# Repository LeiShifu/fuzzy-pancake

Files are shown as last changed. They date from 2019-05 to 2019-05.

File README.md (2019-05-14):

# fuzzy-pancake
A micro bi-axial tensile testing machine designed for biological materials。

load speed：0.0001-0.5mm/s 
data range：0.1-1000gf
accuracy：±0.2% of load range

最近比较忙，先传一部分资料，BOM表过一段时间上传，如果真的有想做的请先联系我，有一些问题还是发语音更能说清楚。

其实双轴拉伸机原理很简单，两边夹具恒速度往外拉伸，再加个力传感器测拉力就好。
至于为什么用arduino，因为确实省事。。。

设计思路：机械部分+控制部分

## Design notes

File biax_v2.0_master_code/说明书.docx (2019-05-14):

0-8这几个数字的功能和以前的sv，sr，n，p，l一样。。。

a-w用来设置速度

默认的速度为0，默认的预加载拉力为10g

例如：设置y轴速度为0.1mm/s就在串口输入AE （A:设置y轴速度为0，E：y轴速度+0.1mm/s）

默认x和y轴都会动，恒速度加载再输入1就行

如果在加载中途y轴要改成0.01mm/s的话输入AH1(A:设置y轴速度为0，H：y轴速度+0.01mm/s，1：在这里的作用是更新速度，如果没输入1的话拉伸机夹具的速度还是0.1mm/s)

case 0:motor_stop();motor_start_flag=0;break;//模式0,电机停止(停止加载)

case 1:motor_start_flag=motor_start(SetSpeed);break;//模式1，恒速度加载

case 2:start_run_force_flag=1;break; //模式2，恒力加载

case 3:start_run_repetition_flag=1;break;//模式3，预加载

case 4:motor_start_flag=1;break; //模式4，输出数据

case 5:motor_start_flag=0;break; //模式5，停止输出数据

case 6:reset_zero_flag=1;break; //模式6，位置归零

case 7:calibrate_flag=1;break; //模式7，传感器归零

case 8:reverse_dir_flag=1;break; //模式8，反向

小写字母(a-w)设置x轴的值，大写字母(A-W)设置y轴的值。

case 'a':x_start(20);break; //设置x轴速度为0

case 'b':x_start(21);break; //设置x轴速度加1mm/s

case 'c':x_start(22);break; //设置x轴速度加0.5mm/s

case 'd':x_start(23);break; //设置x轴速度加0.2mm/s

case 'e':x_start(24);break; //设置x轴速度加0.1mm/s

case 'f':x_start(25);break; //设置x轴速度加0.05mm/s

case 'g':x_start(26);break; //设置x轴速度加0.02mm/s

case 'h':x_start(27);break; //设置x轴速度加0.01mm/s

case 'i':x_start(28);break; //设置x轴速度加0.005mm/s

case 'j':x_start(29);break; //设置x轴速度加0.002mm/s

case 'k':x_start(30);break; //设置x轴速度加0.001mm/s

case 'l':x_start(31);break; //设置x轴速度加0.0005mm/s

case 'm':x_start(32);break; //设置x轴速度加0.0002mm/s

case 'n':x_start(33);break; //设置x轴速度加0.0001mm/s

case 'o':x_start(40);break;//设置x轴最大拉力为0(应力松弛实验才会用到）

case 'p':x_start(41);break; //设置x轴最大拉力加50g

case 'q':x_start(42);break; //设置x轴最大拉力加20g

case 'r':x_start(43);break; //设置x轴最大拉力加10g

case 's':x_start(44);break; //设置x轴最大拉力加5g

case 't':x_start(45);break; //设置x轴最大拉力加2g

case 'u':x_start(46);break; //设置x轴最大拉力加1g

case 'v':x_start(47);break; //设置预拉伸拉力为0

case 'w':x_start(48);break; //设置预拉伸拉力加1g

拉伸机上有夹具的轴是y轴，所以这两行命令应该不用管。。。

case 'X':y_enable=0;break; //停用y轴（单轴拉伸）

case 'Y':y_enable=1;break; //启用y轴（双轴拉伸）

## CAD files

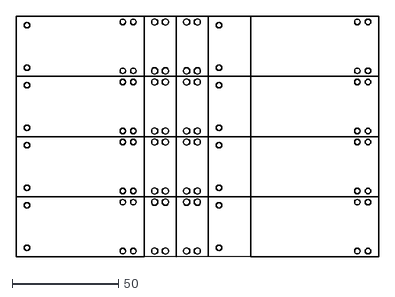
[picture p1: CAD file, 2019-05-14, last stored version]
Drawing2.dxf
170.4 x 112.8

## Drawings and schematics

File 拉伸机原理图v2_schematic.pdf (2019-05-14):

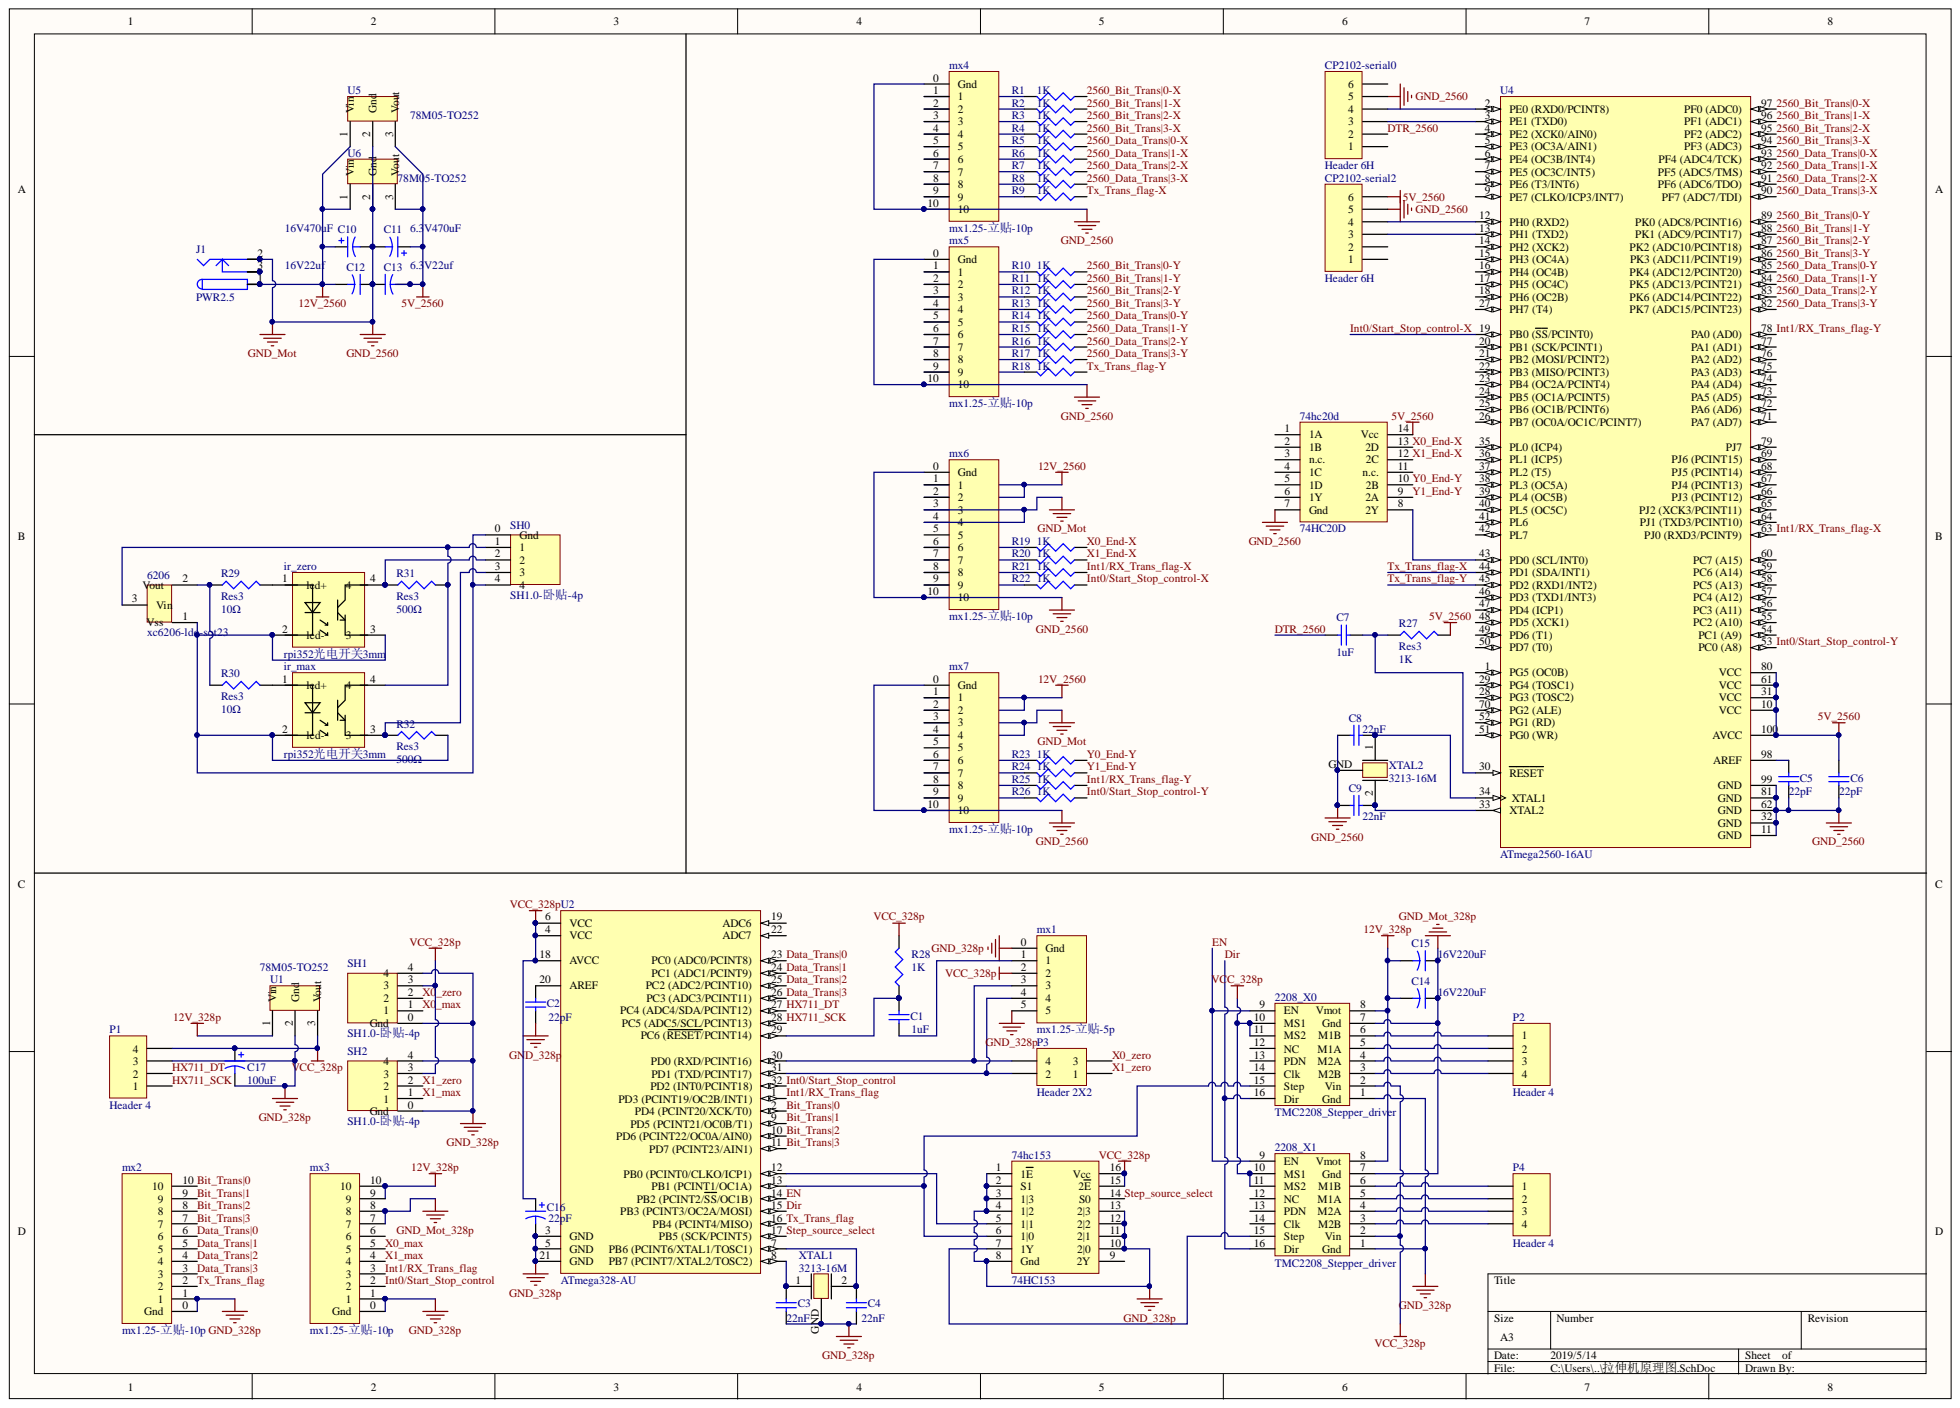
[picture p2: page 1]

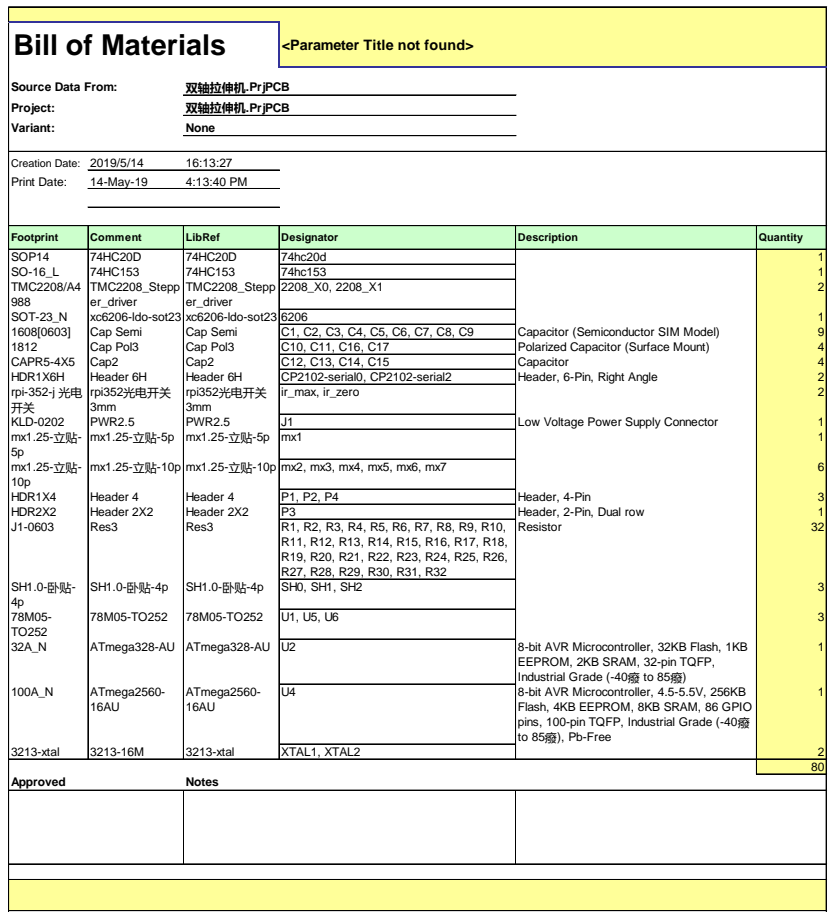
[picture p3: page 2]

EEPROM, 2KB SRAM, 32-pin TQFP,
Industrial Grade (-40癈 to 85癈)

Flash, 4KB EEPROM, 8KB SRAM, 86 GPIO
pins, 100-pin TQFP, Industrial Grade (-40癈
to 85癈), Pb-Free

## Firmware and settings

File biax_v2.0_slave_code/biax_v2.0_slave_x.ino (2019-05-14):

#include "HX711.h"
#include "STEP.h"

void runcountrol();
void SendForce();
void init_conmunication_io();
void start_run_repetition();
void start_run_force(double force_speed);
long get_data();

uint8_t recieved_data[8];
uint8_t force_data[4];
uint8_t Bit;
double SetSpeed=0,SetForce=0,SetPreForce=100;

bool motor_start_flag=0;
bool start_run_flag=0;
bool start_run_repetition_flag=0;//预加载
bool start_run_force_flag=0;     //恒力加载
bool reset_zero_flag=0;          //位置归零
bool calibrate_flag=0;           //校准
bool reverse_dir_flag=0;         //反向

void setup(){
  init_motor_io();
  Init_Hx711();
  init_conmunication_io();
  attachInterrupt(0, runcountrol,RISING);
  calibrate();
  reset_zero();
}

void loop(){
  if(motor_start_flag){
    long Force=Get_Force();
    if(Force>0){
      force_data[0]=Force%10;
      Force/=10;
      force_data[1]=Force%10;
      Force/=10;
      force_data[2]=Force%10;
      Force/=10;
      force_data[3]=Force%10;
    }
    else
      force_data[0]=force_data[1]=force_data[2]=force_data[3]=0; 
    SendForce();
    delay(110);
  }
  if(start_run_repetition_flag){  //预加载
    start_run_repetition_flag=0;
    start_run_repetition();
  }
  if(start_run_force_flag){
    start_run_force_flag=0;     //恒力加载
    start_run_force(SetSpeed);
  }
  if(reset_zero_flag){
   reset_zero_flag=0;          //位置归零
   reset_zero();
  }
  if(calibrate_flag){
    calibrate_flag=0;           //校准
    calibrate();
  }
  if(reverse_dir_flag){
    reverse_dir_flag=0;         //反向
    reverse_dir();
  }
}
void runcountrol(){
  DDRD=0x00;
  DDRC=0xf0&DDRC;
  delayMicroseconds(1);
  DDRD=0x00;
  DDRC=0xf0&DDRC;
  delayMicroseconds(1);
  switch((PIND>>4&0x0f)|(PINC<<4&0xf0)){
    case 0:motor_stop();motor_start_flag=0;break;          //模式0，电机停止
    case 1:motor_start_flag=motor_start(SetSpeed);break;    //模式1，恒速度加载
    case 2:start_run_force_flag=1;break;     //模式2，恒力加载
    case 3:start_run_repetition_flag=1;break;//模式3，预加载
    case 4:motor_start_flag=1;break;        //模式4，输出数据
    case 5:motor_start_flag=0;break;        //模式5，停止输出数据
    case 6:reset_zero_flag=1;break;          //模式6，位置归零
    case 7:calibrate_flag=1;break;           //模式7，校准
    case 8:reverse_dir_flag=1;break;         //模式8，反向
    case 20:SetSpeed=0;break;         //设置速度为0
    case 21:SetSpeed+=1;break;        //速度加1mm/s
    case 22:SetSpeed+=0.5;break;      //速度加0.5mm/s
    case 23:SetSpeed+=0.2;break;      //速度加0.2mm/s
    case 24:SetSpeed+=0.1;break;      //速度加0.1mm/s
    case 25:SetSpeed+=0.05;break;
    case 26:SetSpeed+=0.02;break;
    case 27:SetSpeed+=0.01;break; 
    case 28:SetSpeed+=0.005;break;
    case 29:SetSpeed+=0.002;break;
    case 30:SetSpeed+=0.001;break;
    case 31:SetSpeed+=0.0005;break;
    case 32:SetSpeed+=0.0002;break;
    case 33:SetSpeed+=0.0001;break; 
    case 40:SetForce=0;break;          //设置应力松弛时最大拉力为0
    case 41:SetForce+=500;break;       //最大拉力加50g
    case 42:SetForce+=200;break;       //模式1，恒速度加载
    case 43:SetForce+=100;break;       //模式1，恒速度加载
    case 44:SetForce+=50;break;
    case 45:SetForce+=20;break; 
    case 46:SetForce+=10;break;
    case 47:SetPreForce=0;break;       //设置预拉伸拉力为0
    case 48:SetPreForce+=10;break;     //预拉伸拉力加1g
  }
 DDRD=0b11110000|DDRD;
 DDRC=0b00001111|DDRC;
}

void start_run_force(double force_speed){
  int i=12000;
  long ooo=0;
  motor_start(force_speed);
  while(get_data()<SetForce){
    SendForce();
    delay(100);
  }
  force_speed=force_speed/2;
  while(i>0){
    ooo=get_data();
    if(ooo>SetForce*1.01){
      force_speed=force_speed/2;
      motor_start(force_speed);
    }
    else if(ooo<SetForce*0.99){
      force_speed=force_speed*1.5;
      motor_start(force_speed);
    }
    SendForce();
    delay(100);
    i--;
  }
  motor_stop();
}

long get_data(){
    long nega=Get_Force();
    if(nega>0){
      force_data[0]=nega%10;
      nega/=10;
      force_data[1]=nega%10;
      nega/=10;
      force_data[2]=nega%10;
      nega/=10;
      force_data[3]=nega%10;
    }
    else
      force_data[0]=force_data[1]=force_data[2]=force_data[3]=0; 
    return nega;
}

void start_run_repetition(){
  motor_start(0.05);
  for(int i=0;i<3;i++){
  while(Get_Force()<SetPreForce){
    delay(100);
  }
  reverse_dir();
  while(Get_Force()>0){
    delay(100);
  }
  reverse_dir();
  }
  motor_stop();
}

void SendForce(){
  PORTD=(0x01&PORTD)|0x00;
  PORTC=(0x10&PORTC)|force_data[0];
  bitSet(PORTB,4);
  delayMicroseconds(10);
  bitClear(PORTB,4);
  PORTD=(0x01&PORTD)|0x10;
  PORTC=(0x10&PORTC)|force_data[1];
  bitSet(PORTB,4);
  delayMicroseconds(10);
  bitClear(PORTB,4);
  PORTD=(0x01&PORTD)|0x20;
  PORTC=(0x10&PORTC)|force_data[2];
  bitSet(PORTB,4);
  delayMicroseconds(10);
  bitClear(PORTB,4);
  PORTD=(0x01&PORTD)|0x30;
  PORTC=(0x10&PORTC)|force_data[3];
  bitSet(PORTB,4);
  delayMicroseconds(10);
  bitClear(PORTB,4);
}

void init_conmunication_io(){
  bitSet(DDRC,0);
  bitSet(DDRC,1);
  bitSet(DDRC,2);
  bitSet(DDRC,3);
  bitSet(DDRD,4);
  bitSet(DDRD,5);
  bitSet(DDRD,6);
  bitSet(DDRD,7);
  bitSet(DDRB,4);           //从机发送数据指示位
  bitClear(DDRD,2);         //从机启停控制中断，int0
  bitClear(DDRD,3);         //从机接收数据控制中断，int1
}

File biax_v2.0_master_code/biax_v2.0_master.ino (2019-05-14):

uint8_t x_data[4];
uint8_t y_data[4];

void RecieveXdata();
void RecieveYdata();
void OverRange();
void x_start(uint8_t mode);
void y_start(uint8_t mode);
void print_data();

char comchar;
bool if_start_run=0,y_enable=1;

void setup() {
  DDRF=0x00;             //接收x轴数据
  DDRK=0x00;             //接收y轴数据
  bitSet(DDRJ,0);        //x轴数据传输控制
  bitSet(DDRB,0);        //x轴启停控制
  bitSet(DDRA,0);        //y轴数据传输控制
  bitSet(DDRC,0);        //y轴启停控制
  DDRD=0x00;
  Serial.begin(115200);
  Serial2.begin(115200);
  attachInterrupt(2, OverRange,RISING);
  attachInterrupt(3, RecieveXdata,RISING);
  attachInterrupt(4, RecieveYdata,RISING);
  TCCR1A=0x00;
  TCCR1B=0b00001101;
  TCNT1=0;
  OCR1A=3124;
  Serial.println("format: x-force,y-force, unit:0.1g, f=5hz");
}

void loop() {
  while(Serial.available()>0){
    comchar = Serial.read();    //读串口第一个字节
    switch(comchar){
      case '0':x_start(0);                          //模式0，电机停止
               if(y_enable)
                 y_start(0);
               TIMSK1 &= ~(1 << OCIE1A);break;
      case '1':x_start(1);                          //模式1，恒速度加载
               if(y_enable)
                 y_start(1);
               TIMSK1 |= (1 << OCIE1A);break;
      case '2':x_start(2);                          //模式2，恒力加载
               if(y_enable)
                 y_start(2);
               TIMSK1 |= (1 << OCIE1A);break;
      case '3':x_start(3);                          //模式3，预加载
               if(y_enable)
                 y_start(3);
               TIMSK1 |= (1 << OCIE1A);Serial.println("预加载");break;
      case '4':x_start(4);                         //模式4，输出数据
               if(y_enable)
                 y_start(4);
               TIMSK1 |= (1 << OCIE1A);break; //enable timer1 启用输出数据中断程序
      case '5':x_start(5);                         //模式5，停止输出数据
               if(y_enable)
                 y_start(5);
               TIMSK1 &= ~(1 << OCIE1A);break;//disable timer1
      case '6':x_start(6);                         //模式6，位置归零
               if(y_enable)
                 y_start(6);
               Serial.println("位置归零");break;
      case '7':x_start(7);                         //模式7，校准
               if(y_enable)
                 y_start(7);
               Serial.println("传感器拉力归零");break;
      case '8':x_start(8);                         //模式8，反向
               if(y_enable)
                 y_start(8);
               Serial.println("反向");break;
      
      case 'a':x_start(20);break;  //设置x轴速度为0
      case 'b':x_start(21);break;
      case 'c':x_start(22);break;
      case 'd':x_start(23);break;
      case 'e':x_start(24);break;
      case 'f':x_start(25);break;
      case 'g':x_start(26);break;
      case 'h':x_start(27);break;
      case 'i':x_start(28);break;
      case 'j':x_start(29);break;
      case 'k':x_start(30);break;
      case 'l':x_start(31);break;
      case 'm':x_start(32);break;
      case 'n':x_start(33);break;
      case 'o':x_start(40);break;  //设置x轴力为0
      case 'p':x_start(41);break;
      case 'q':x_start(42);break;
      case 'r':x_start(43);break;
      case 's':x_start(44);break;
      case 't':x_start(45);break;
      case 'u':x_start(46);break;
      case 'v':x_start(47);break;
      case 'w':x_start(48);break;
      case 'A':y_start(20);break;  //设置y轴速度为0
      case 'B':y_start(21);break;
      case 'C':y_start(22);break;
      case 'D':y_start(23);break;
      case 'E':y_start(24);break;
      case 'F':y_start(25);break;
      case 'G':y_start(26);break;
      case 'H':y_start(27);break;
      case 'I':y_start(28);break;
      case 'J':y_start(29);break;
      case 'K':y_start(30);break;
      case 'L':y_start(31);break;
      case 'M':y_start(32);break;
      case 'N':y_start(33);break;
      case 'O':y_start(40);break;   //设置y轴力为0
      case 'P':y_start(41);break;
      case 'Q':y_start(42);break;
      case 'R':y_start(43);break;
      case 'S':y_start(44);break;
      case 'T':y_start(45);break;
      case 'U':y_start(46);break;
      case 'V':y_start(47);break;
      case 'W':y_start(48);break;
      
      case 'X':y_enable=0;break;    //停用y轴（单轴拉伸）
      case 'Y':y_enable=1;break;    //启用y轴（双轴拉伸）
    }
  }
  delay(2); 
  if(if_start_run){
    if_start_run=0;
    print_data();
  }
}

ISR(TIMER1_COMPA_vect){
  if_start_run=1;
}

void RecieveXdata(){
  x_data[PINF&0x0f]=PINF>>4;
}

void RecieveYdata(){
  y_data[PINK&0x0f]=PINK>>4;
}

void OverRange(){
  
}

void y_start(uint8_t mode){
  DDRK=0xff;
  PORTK=mode;
  PORTC=0xFF;
  delayMicroseconds(25);
  PORTC=0x00;
  DDRK=0x00;
}

void x_start(uint8_t mode){
  DDRF=0xff;
  PORTF=mode;
  PORTB=0xFF;
  delayMicroseconds(25);
  PORTB=0x00;
  DDRF=0x00;
}

void print_data(){
  Serial.print("x");
  for(int i=3;i>=0;i--)
    Serial.print(x_data[i]);
  Serial.print("y");
  for(int i=3;i>=0;i--)
    Serial.print(y_data[i]);
  Serial.print('\n');
}
